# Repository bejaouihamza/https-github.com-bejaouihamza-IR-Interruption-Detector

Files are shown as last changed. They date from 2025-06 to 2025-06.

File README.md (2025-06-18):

# 🔦 IR Interruption Detector PCB

This project is a complete PCB-based system that detects interruptions between an **IR emitter and receiver**. When an object blocks the IR beam:
- A **buzzer/speaker** is triggered,
- A **7-segment display counter** is incremented,
- A **reset button** clears the count.

The circuit is entirely based on **discrete components**, including **NE555 timers**, **CD40106**, and a **CD4033** counter/decoder. It also includes a **robust regulated power supply**, and can be used in security, object-counting, or automation systems.

---

## 📷 Schematic
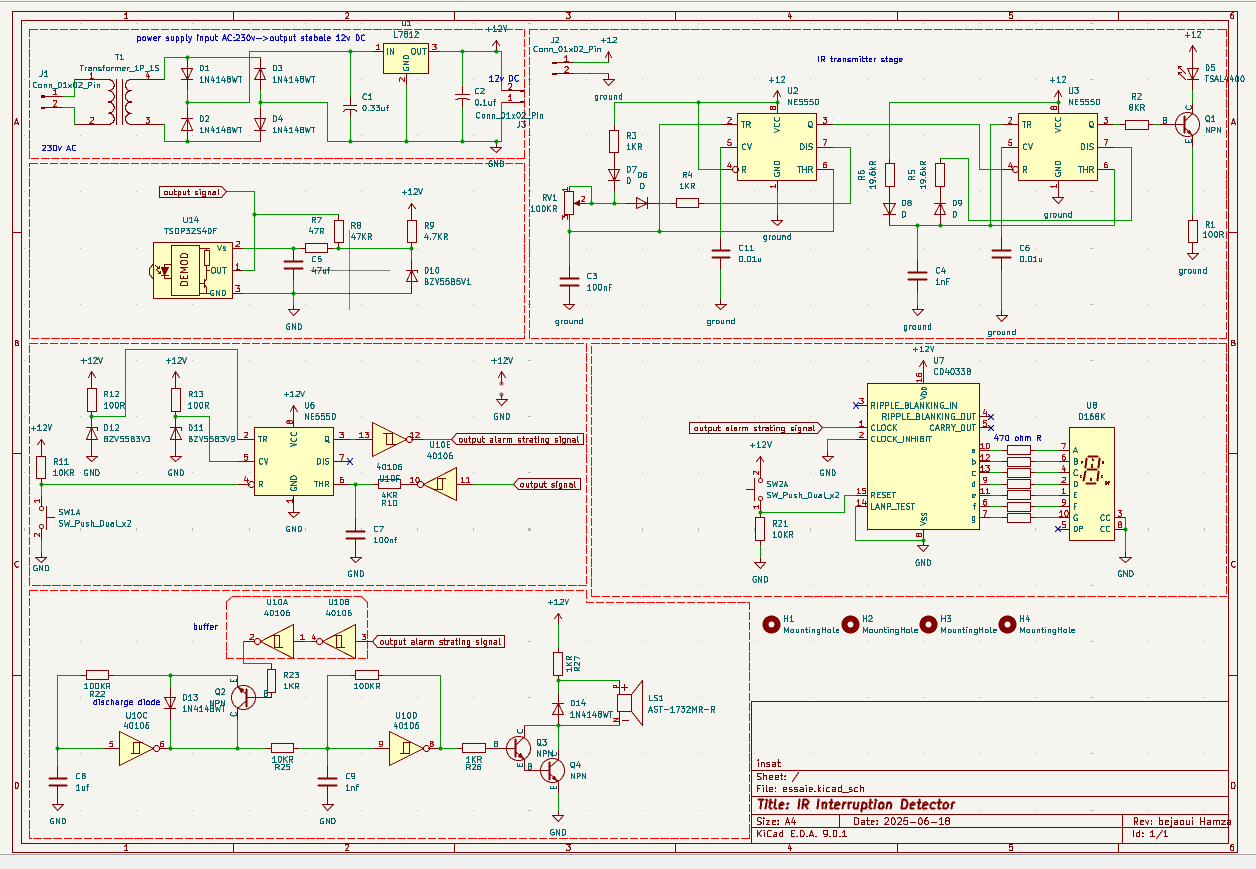
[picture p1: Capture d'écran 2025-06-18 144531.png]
Schematic


---

## 🧩 PCB Layout
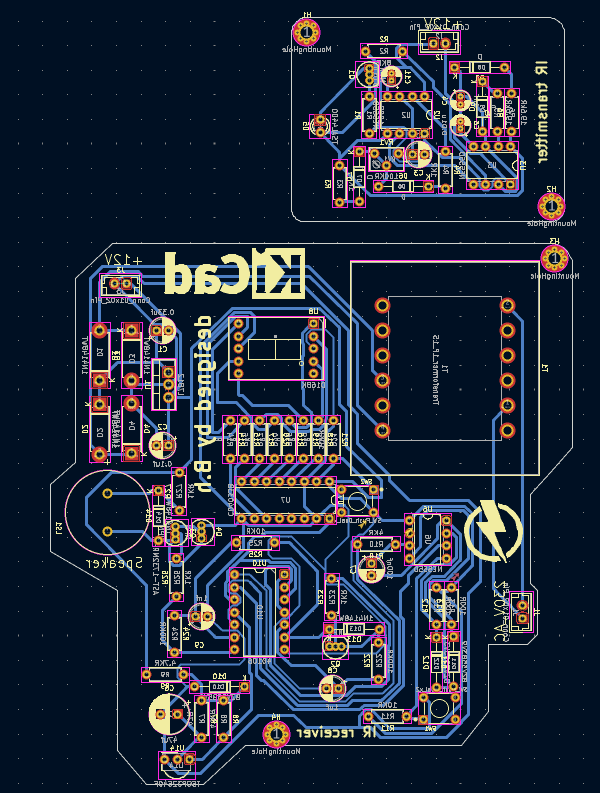
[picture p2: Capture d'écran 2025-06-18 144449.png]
PCB


---

## 🧱 3D Model
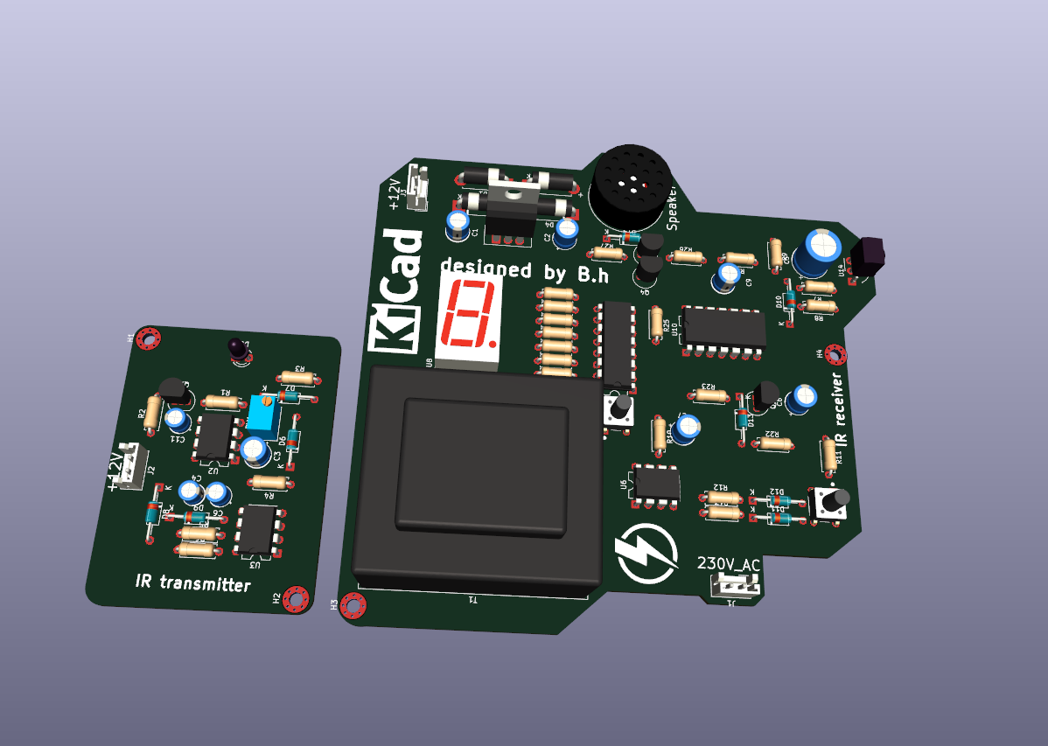
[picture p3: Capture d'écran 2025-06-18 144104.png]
3D Model


---

## ⚙️ System Overview

### ➤ Power Supply
The power input is **230V AC**, stepped down using a transformer and rectified via a **bridge diode**. The output is regulated to **+12V DC** using a **7812 voltage regulator**.

---

### ➤ IR Transmitter Stage

- **Components**: 2x NE555 + TSAL4400 IR LED
- The first NE555 generates a **square wave** (~38 kHz), modulated by the second NE555 to create an **amplitude-modulated IR beam**.
- Transistor **Q1** amplifies the signal and drives the IR LED with enough current.

---

### ➤ IR Receiver & Detection

- **TSOP2254** is used to receive the modulated IR beam.
- Its digital output goes **LOW** when it detects the 38 kHz signal.
- When an interruption occurs (e.g. hand/object blocks the beam), the output goes **HIGH**, triggering further stages.

---

### ➤ Signal Conditioning & Alarm Logic

- NE555 (U6) is configured in a monostable mode.
- CD40106 Schmitt triggers (U2, U3) are used for **clean signal shaping** and logic handling.
- This ensures only valid interruptions trigger the output.

---

### ➤ Output Stage

- A speaker or buzzer (AST-1732MR-R) is triggered via transistor Q3.
- An LED also indicates the alarm visually.

---

### ➤ Counting Stage

- A **CD4033B** 7-segment BCD counter increments with each IR interruption.
- A **D168K** display shows the count.
- A reset button allows clearing the count manually.

---

## 🔁 Workflow Summary

1. **Idle**: IR signal is received, no object interrupting.
2. **Interrupt**: Object breaks the beam → TSOP output goes HIGH.
3. **Detection**: NE555 monostable timer triggers.
4. **Alarm**: Buzzer sounds + 7segments Display increments count.
5. **Reset**: Pressing the reset button clears the counter.

---

## 🧰 Bill of Materials (BOM)

| Component | Quantity | Notes |
|---|---|---|
| NE555 | 3 | Signal modulation and detection |
| TSOP2254 | 1 | IR receiver |
| TSAL4400 | 1 | IR LED |
| CD40106 | 1 | Schmitt trigger inverter |
| CD4033B | 1 | BCD Counter |
| D168K | 1 | 7-Segment Display |
| AST-1732MR-R  | 1 | Buzzer/Speaker |
| Q1, Q2, Q3 | 3 | NPN transistors |
| TP4056 | 1 (opt.) | Optional for battery version |
| AMS1117-3.3 | 1 (opt.) | Optional for low-voltage designs |

---

## 🔧 Tools Used

- **KiCad 9** for schematic and PCB design
- **Open source components**
- **Through-hole components **

---

## 🧠 Author

Designed by **Bejaoui Hamza**  
Date: **18 June 2025**  
Project name: `IR Interruption Detector`

---

## 📂 License

This project is open-source under the [MIT License](LICENSE).

---

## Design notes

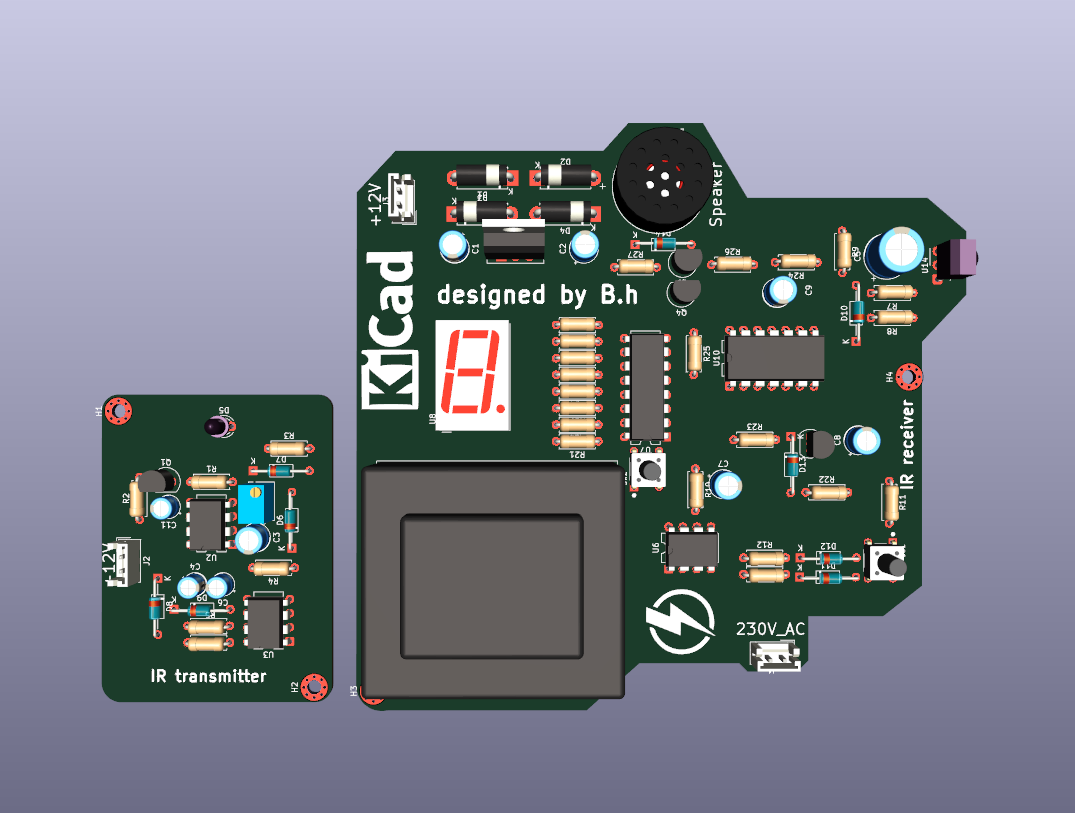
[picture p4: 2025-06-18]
Capture d'écran 2025-06-18 144140.png

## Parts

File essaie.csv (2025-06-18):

Reference | Value | Footprint | Datasheet | Qty | DNP | Exclude from BOM | Exclude from Board
C1 | 0.33uf | Capacitor_THT:CP_Radial_D5.0mm_P2.50mm |  | 1
C2 | 0.1uf | Capacitor_THT:CP_Radial_D5.0mm_P2.50mm |  | 1
C3 | 100nF | Capacitor_THT:CP_Radial_D5.0mm_P2.50mm | ~ | 1
C4 | 1nF | Capacitor_THT:CP_Radial_D4.0mm_P1.50mm | ~ | 1
C5 | 47uf | Capacitor_THT:CP_Radial_D8.0mm_P3.50mm | ~ | 1
C6,C11 | 0.01u | Capacitor_THT:CP_Radial_D4.0mm_P1.50mm | ~ | 2
C7 | 100nf | Capacitor_THT:CP_Radial_D5.0mm_P2.50mm | ~ | 1
C8 | 1uf | Capacitor_THT:CP_Radial_D5.0mm_P2.50mm | ~ | 1
C9 | 1nf | Capacitor_THT:CP_Radial_D5.0mm_P2.50mm | ~ | 1
D1,D2,D3,D4 | 1N4148WT | Diode_THT:D_5W_P10.16mm_Horizontal | https://www.diodes.com/assets/Datasheets/ds30396.pdf | 4
D5 | TSAL4400 | LED_THT:LED_D3.0mm_IRBlack | http://www.vishay.com/docs/81006/tsal4400.pdf | 1
D6,D7,D8,D9 | D | Diode_THT:D_DO-35_SOD27_P10.16mm_Horizontal | ~ | 4
D10 | BZV55B5V1 | Diode_THT:D_DO-35_SOD27_P10.16mm_Horizontal | https://assets.nexperia.com/documents/data-sheet/BZV55_SER.pdf | 1
D11 | BZV55B3V9 | Diode_THT:D_DO-35_SOD27_P10.16mm_Horizontal | https://assets.nexperia.com/documents/data-sheet/BZV55_SER.pdf | 1
D12 | BZV55B3V3 | Diode_THT:D_DO-35_SOD27_P10.16mm_Horizontal | https://assets.nexperia.com/documents/data-sheet/BZV55_SER.pdf | 1
D13,D14 | 1N4148WT | Diode_THT:D_DO-35_SOD27_P10.16mm_Horizontal | https://www.diodes.com/assets/Datasheets/ds30396.pdf | 2
H1,H2,H3,H4 | MountingHole | MountingHole:MountingHole_2.5mm_Pad_Via | ~ | 4 |  | Exclure de la Liste du Matériel
J1,J2,J3 | Conn_01x02_Pin | Connector_JST:JST_EH_B2B-EH-A_1x02_P2.50mm_Vertical | ~ | 3
LS1 | AST-1732MR-R | footprints:SPKR_AST-1732MR-R |  | 1
Q1,Q2,Q3,Q4 | NPN | Package_TO_SOT_THT:TO-92_Inline | https://ngspice.sourceforge.io/docs/ngspice-html-manual/manual.xhtml#cha_BJTs | 4
R1,R12,R13 | 100R | Resistor_THT:R_Axial_DIN0207_L6.3mm_D2.5mm_P7.62mm_Horizontal | ~ | 3
R2 | 8KR | Resistor_THT:R_Axial_DIN0207_L6.3mm_D2.5mm_P7.62mm_Horizontal | ~ | 1
R3,R4,R23,R26,R27 | 1KR | Resistor_THT:R_Axial_DIN0207_L6.3mm_D2.5mm_P7.62mm_Horizontal | ~ | 5
R5,R6 | 19.6kR | Resistor_THT:R_Axial_DIN0207_L6.3mm_D2.5mm_P7.62mm_Horizontal | ~ | 2
R7 | 47R | Resistor_THT:R_Axial_DIN0207_L6.3mm_D2.5mm_P7.62mm_Horizontal | ~ | 1
R8 | 47KR | Resistor_THT:R_Axial_DIN0207_L6.3mm_D2.5mm_P7.62mm_Horizontal | ~ | 1
R9 | 4.7KR | Resistor_THT:R_Axial_DIN0207_L6.3mm_D2.5mm_P7.62mm_Horizontal | ~ | 1
R10 | 4KR | Resistor_THT:R_Axial_DIN0207_L6.3mm_D2.5mm_P7.62mm_Horizontal | ~ | 1
R11,R21,R25 | 10KR | Resistor_THT:R_Axial_DIN0207_L6.3mm_D2.5mm_P7.62mm_Horizontal | ~ | 3
R14,R15,R16,R17,R18,R19,R20 | R | Resistor_THT:R_Axial_DIN0207_L6.3mm_D2.5mm_P7.62mm_Horizontal | ~ | 7
R22,R24 | 100KR | Resistor_THT:R_Axial_DIN0207_L6.3mm_D2.5mm_P7.62mm_Horizontal | ~ | 2
RV1 | 100KR | Potentiometer_THT:Potentiometer_Bourns_3266W_Vertical | ~ | 1
SW1,SW2 | SW_Push_Dual_x2 | footprints:SW_FSM8JH | ~ | 2
T1 | Transformer_1P_1S | Transformer_THT:Transformer_37x44 | ~ | 1
U1 | L7812 | Package_TO_SOT_THT:TO-220-3_Vertical | http://www.st.com/content/ccc/resource/technical/document/datasheet/41/4f/b3/b0/12/d4/47/88/CD00000444.pdf/files/CD00000444.pdf/jcr:content/translations/en.CD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 | 1
U2,U3,U6 | NE555D | Package_DIP:DIP-8_W7.62mm | http://www.ti.com/lit/ds/symlink/ne555.pdf | 3
U7 | CD4033B | Package_DIP:DIP-16_W7.62mm | https://www.ti.com/lit/ds/symlink/cd4033b.pdf | 1
U8 | D168K | Display_7Segment:D1X8K | https://ia800903.us.archive.org/24/items/CTKD1x8K/Cromatek%20D168K.pdf | 1
U10 | 40106 | Package_DIP:DIP-14_W10.16mm | https://assets.nexperia.com/documents/data-sheet/HEF40106B.pdf | 1
U14 | TSOP32S40F | OptoDevice:Vishay_MOLD-3Pin | http://www.vishay.com/docs/82669/tsop32s40f.pdf | 1

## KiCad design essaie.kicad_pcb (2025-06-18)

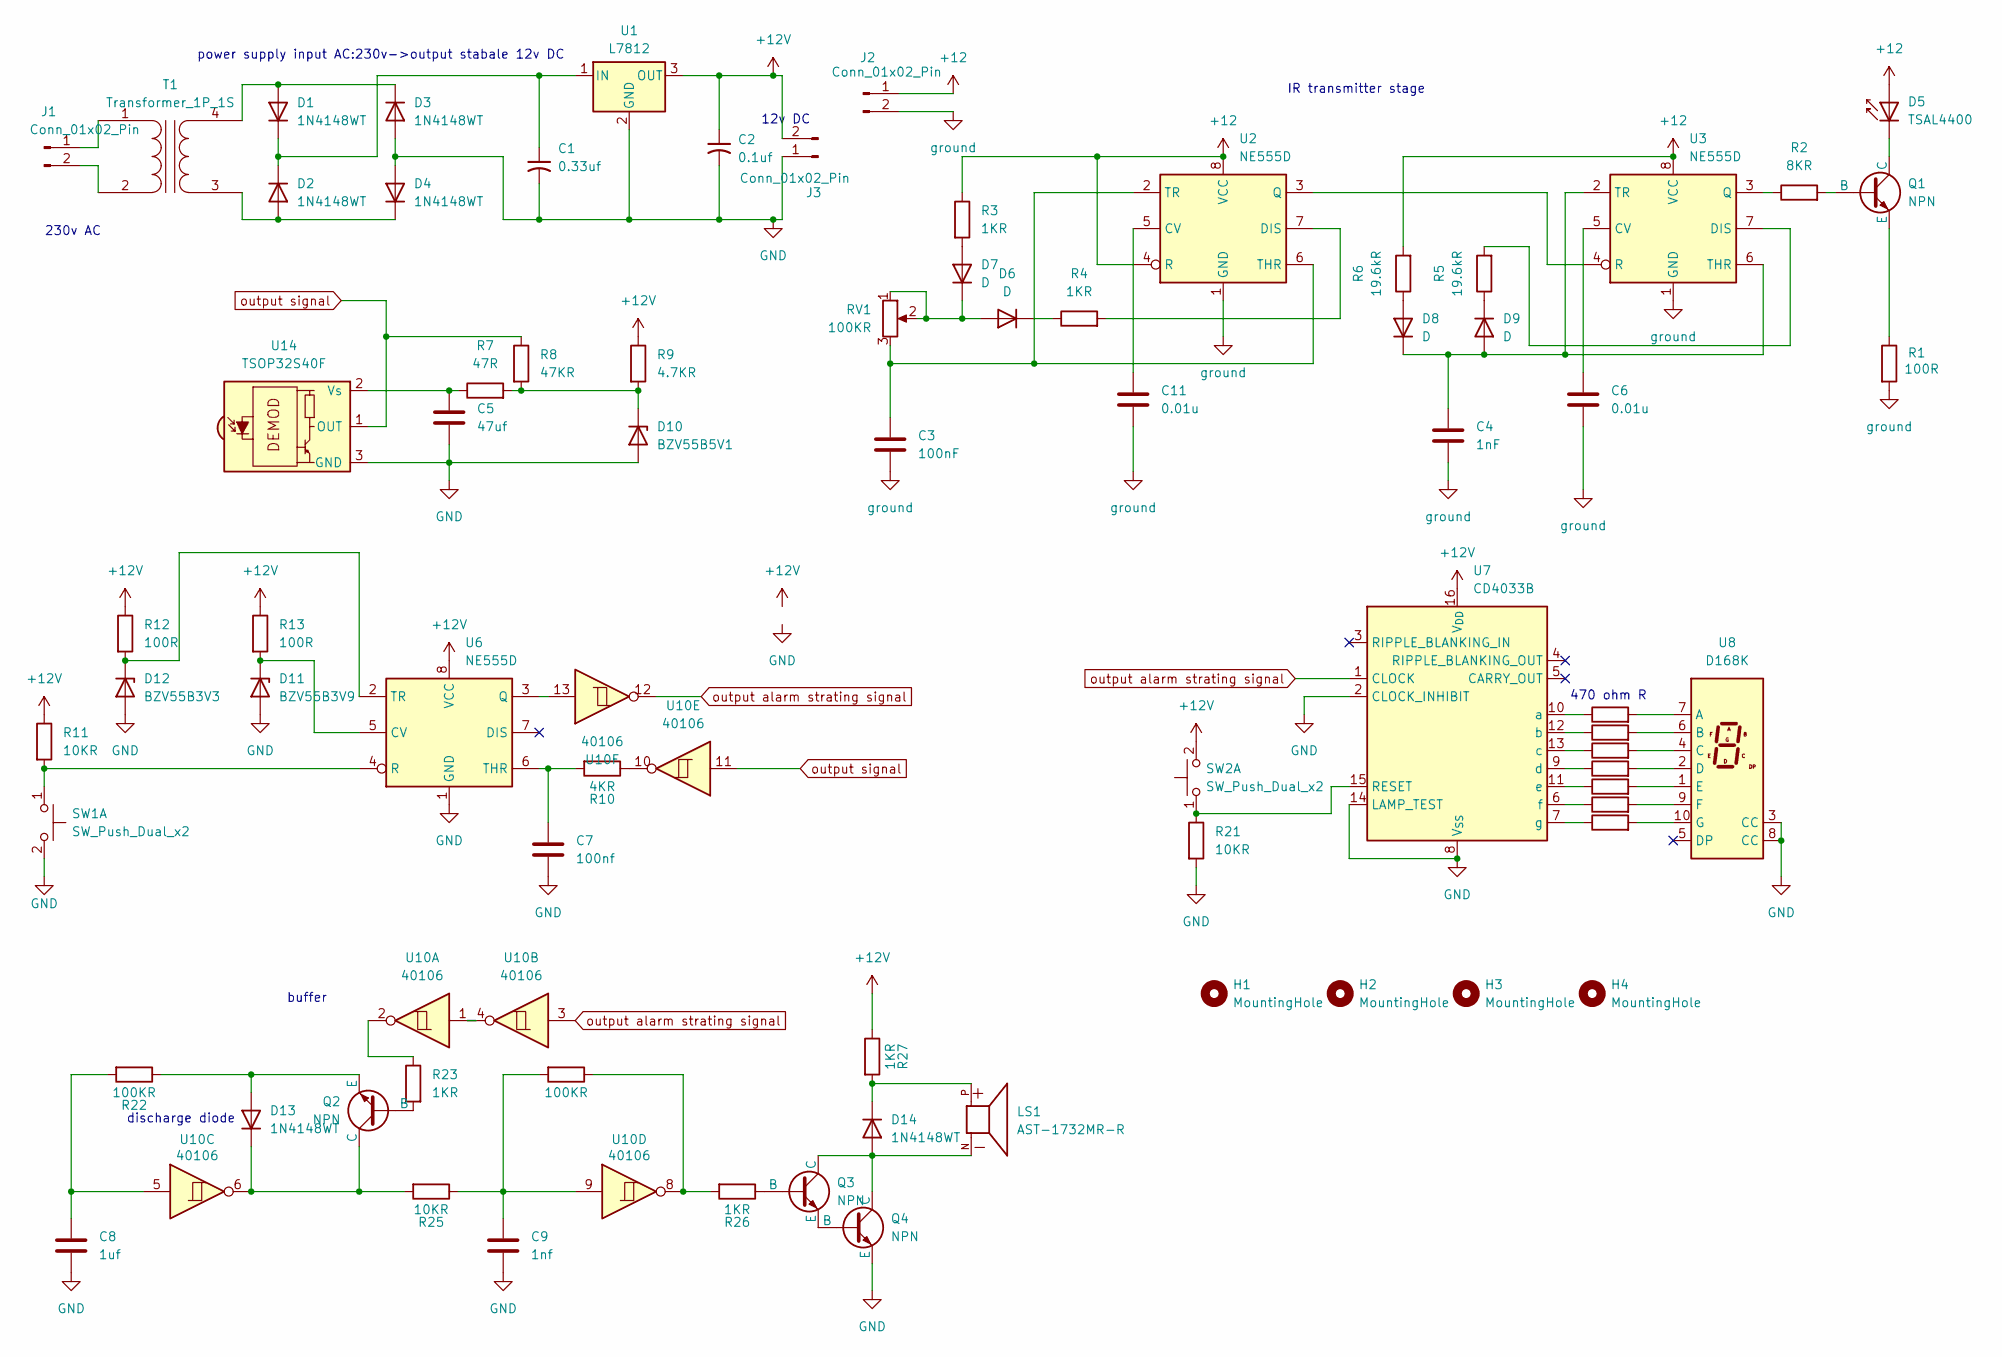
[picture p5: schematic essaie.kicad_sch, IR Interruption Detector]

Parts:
C1: 0.33uf; CP_Radial_D5.0mm_P2.50mm
C2: 0.1uf; CP_Radial_D5.0mm_P2.50mm
C3: 100nF; CP_Radial_D5.0mm_P2.50mm
C4: 1nF; CP_Radial_D4.0mm_P1.50mm
C5: 47uf; CP_Radial_D8.0mm_P3.50mm
C6, C11: 0.01u; CP_Radial_D4.0mm_P1.50mm
C7: 100nf; CP_Radial_D5.0mm_P2.50mm
C8: 1uf; CP_Radial_D5.0mm_P2.50mm
C9: 1nf; CP_Radial_D5.0mm_P2.50mm
D1, D2, D3, D4: 1N4148WT; D_5W_P10.16mm_Horizontal
D5: TSAL4400; LED_D3.0mm_IRBlack
D6, D7, D8, D9: D; D_DO-35_SOD27_P10.16mm_Horizontal
D10: BZV55B5V1; D_DO-35_SOD27_P10.16mm_Horizontal
D11: BZV55B3V9; D_DO-35_SOD27_P10.16mm_Horizontal
D12: BZV55B3V3; D_DO-35_SOD27_P10.16mm_Horizontal
D13, D14: 1N4148WT; D_DO-35_SOD27_P10.16mm_Horizontal
H1, H2, H3, H4: MountingHole; MountingHole_2.5mm_Pad_Via
J1, J2, J3: Conn_01x02_Pin; JST_EH_B2B-EH-A_1x02_P2.50mm_Vertical
LS1: AST-1732MR-R; SPKR_AST-1732MR-R; PARTREV C
Q1, Q2, Q3, Q4: NPN; TO-92_Inline
R1, R12, R13: 100R; R_Axial_DIN0207_L6.3mm_D2.5mm_P7.62mm_Horizontal
R2: 8KR; R_Axial_DIN0207_L6.3mm_D2.5mm_P7.62mm_Horizontal
R3, R4, R23, R26, R27: 1KR; R_Axial_DIN0207_L6.3mm_D2.5mm_P7.62mm_Horizontal
R5, R6: 19.6kR; R_Axial_DIN0207_L6.3mm_D2.5mm_P7.62mm_Horizontal
R7: 47R; R_Axial_DIN0207_L6.3mm_D2.5mm_P7.62mm_Horizontal
R8: 47KR; R_Axial_DIN0207_L6.3mm_D2.5mm_P7.62mm_Horizontal
R9: 4.7KR; R_Axial_DIN0207_L6.3mm_D2.5mm_P7.62mm_Horizontal
R10: 4KR; R_Axial_DIN0207_L6.3mm_D2.5mm_P7.62mm_Horizontal
R11, R21, R25: 10KR; R_Axial_DIN0207_L6.3mm_D2.5mm_P7.62mm_Horizontal
R14, R15, R16, R17, R18, R19, R20: R; R_Axial_DIN0207_L6.3mm_D2.5mm_P7.62mm_Horizontal
R22, R24: 100KR; R_Axial_DIN0207_L6.3mm_D2.5mm_P7.62mm_Horizontal
RV1: 100KR; Potentiometer_Bourns_3266W_Vertical
SW1, SW2: SW_Push_Dual_x2; SW_FSM8JH
T1: Transformer_1P_1S; Transformer_37x44
U1: L7812; TO-220-3_Vertical
U2, U3, U6: NE555D; DIP-8_W7.62mm
U7: CD4033B; DIP-16_W7.62mm
U8: D168K; D1X8K
U10: 40106; DIP-14_W10.16mm
U14: TSOP32S40F; Vishay_MOLD-3Pin

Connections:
+12: D5.2 (A), J2.1, R3.1, R6.2, U2.4 (R), U2.8 (VCC), U3.8 (VCC)
+12V: C2.1, J3.2, R9.1, R11.1, R12.1, R13.1, R27.1, SW2.2 (D), U1.3 (OUT), U6.8 (VCC), U7.16 (V_{DD})
GND: C1.2, C2.2, C5.2, C7.2, C8.2, C9.2, D3.2 (A), D4.2 (A), D10.2 (A), D11.2 (A), D12.2 (A), J3.1, Q4.3 (E), R21.2, SW1.2 (D), U1.2 (GND), U6.1 (GND), U7.2 (CLOCK_INHIBIT), U7.8 (V_{SS}), U7.14 (LAMP_TEST), U8.3 (CC), U8.8 (CC), U14.3 (GND)
unnamed: C8.1, R22.2, U10.5
unnamed: C9.1, R24.2, R25.1, U10.9
unnamed: D1.2 (A), D3.1 (K), T1.4 (SB)
unnamed: C1.1, D1.1 (K), D2.1 (K), U1.1 (IN)
unnamed: D2.2 (A), D4.1 (K), T1.3 (SA)
unnamed: D5.1 (K), Q1.1 (C)
unnamed: D6.2 (A), D7.1 (K), RV1.1, RV1.2
unnamed: D6.1 (K), R4.1
unnamed: D7.2 (A), R3.2
unnamed: D8.2 (A), R6.1
unnamed: C4.1, D8.1 (K), D9.2 (A), U3.2 (TR), U3.6 (THR)
unnamed: D9.1 (K), R5.1
unnamed: D10.1 (K), R7.2, R8.2, R9.2
unnamed: D11.1 (K), R13.2, U6.5 (CV)
unnamed: D12.1 (K), R12.2, U6.2 (TR)
unnamed: D13.2 (A), Q2.3 (E), R22.1
unnamed: D13.1 (K), Q2.1 (C), R25.2, U10.6
unnamed: D14.2 (A), LS1.N, Q3.1 (C), Q4.1 (C)
unnamed: D14.1 (K), LS1.P, R27.2
unnamed: J1.1, T1.1 (AA)
unnamed: J1.2, T1.2 (AB)
unnamed: Q1.2 (B), R2.2
unnamed: Q1.3 (E), R1.1
unnamed: Q2.2 (B), R23.2
unnamed: Q3.2 (B), R26.1
unnamed: Q3.3 (E), Q4.2 (B)
unnamed: R10.1, U10.10
unnamed: R23.1, U10.2
unnamed: R24.1, R26.2, U10.8
unnamed: R11.2, SW1.1 (C), U6.4 (R)
unnamed: R21.1, SW2.1 (C), U7.15 (RESET)
unnamed: C11.1, U2.5 (CV)
unnamed: R4.2, U2.7 (DIS)
unnamed: U2.3 (Q), U3.4 (R)
unnamed: C3.1, RV1.3, U2.2 (TR), U2.6 (THR)
unnamed: C6.1, U3.5 (CV)
unnamed: R5.2, U3.7 (DIS)
unnamed: R2.1, U3.3 (Q)
unnamed: U6.3 (Q), U10.13
unnamed: C7.1, R10.2, U6.6 (THR)
unnamed: R20.1, U7.10 (a)
unnamed: R19.1, U7.12 (b)
unnamed: R18.1, U7.13 (c)
unnamed: R17.1, U7.9 (d)
unnamed: R16.1, U7.11 (e)
unnamed: R15.1, U7.6 (f)
unnamed: R14.1, U7.7 (g)
unnamed: R20.2, U8.7 (A)
unnamed: R19.2, U8.6 (B)
unnamed: R18.2, U8.4 (C)
unnamed: R17.2, U8.2 (D)
unnamed: R16.2, U8.1 (E)
unnamed: R15.2, U8.9 (F)
unnamed: R14.2, U8.10 (G)
unnamed: U10.1, U10.4
unnamed: C5.1, R7.1, U14.2 (Vs)
ground: C3.2, C4.2, C6.2, C11.2, J2.2, R1.2, U2.1 (GND), U3.1 (GND)
output alarm strating signal: U7.1 (CLOCK), U10.3, U10.12
output signal: R8.1, U10.11, U14.1 (OUT)

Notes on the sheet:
12v DC
buffer
230v AC
IR transmitter stage
discharge diode
470 ohm R
power supply input AC:230v->output stabale 12v DC

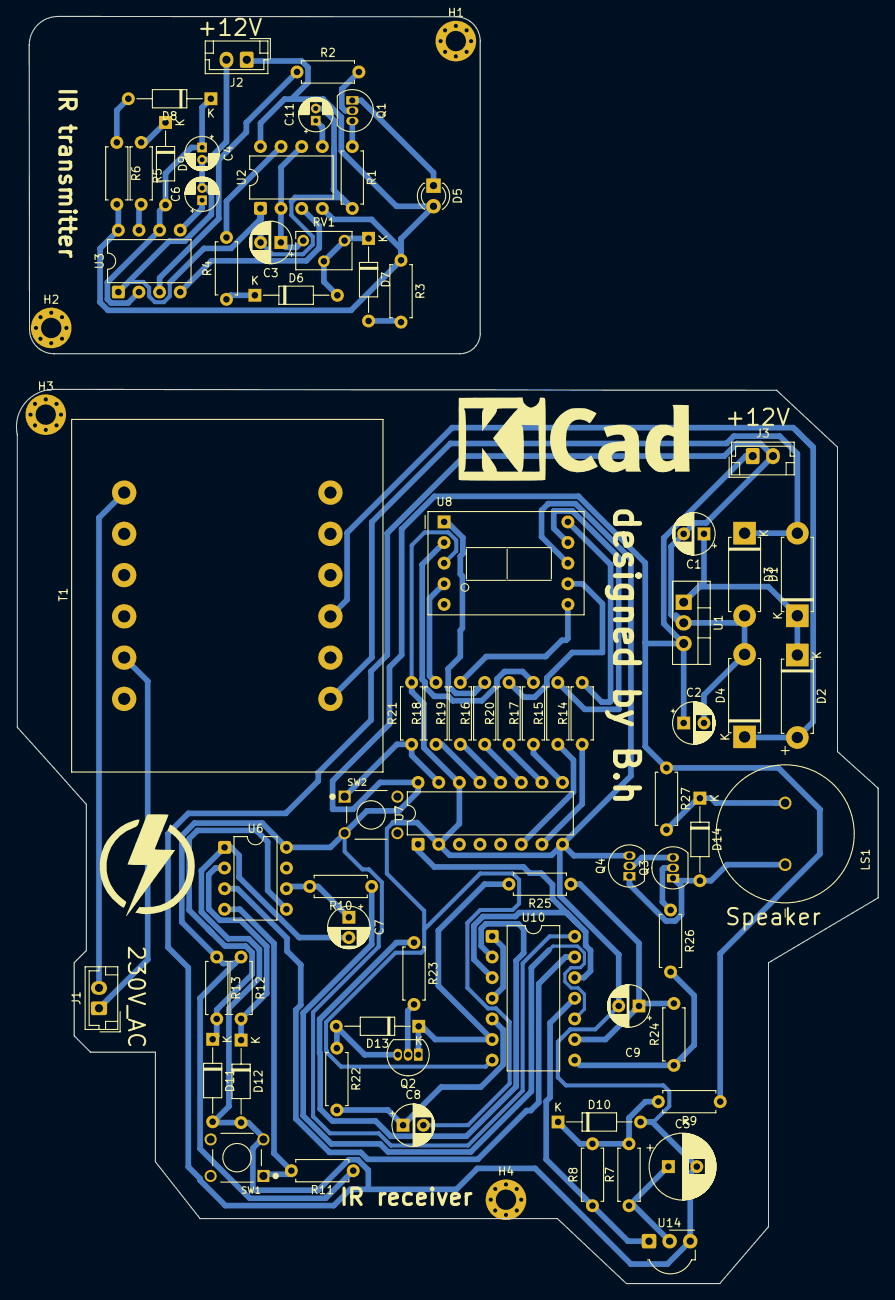
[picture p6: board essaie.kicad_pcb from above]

Board: 2 copper layers, 106.1 x 156.0 mm, 75 parts (0 on the bottom side), 62 nets.
